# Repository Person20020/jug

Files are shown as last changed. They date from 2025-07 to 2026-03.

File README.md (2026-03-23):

Jug Logo wide no fill

# Jug

A 6x3 column staggered split keyboard with a large thumb cluster.



jug render

The jug is a 6x3 column staggered split keyboard with 46 keys. It has a 5 key thumb cluster extending out to reduce reaching back with your thumb. It uses USB C for interconnect and includes two indicator leds per side for caps/num lock and layer (eg. Colemak vs QWERTY).

The PCB supports both hotswap sockets and directly soldering the switches. It is fully reversible and uses soldered jumpers for the MCU, a RP2040 Zero.

All components are placed so that the case sides are exact mirrors.

pcb
schematic
routing

## Parts

### Electronics

| Part | Count | Price ($) | Link |
| --- | ----- | --- | --- |
| RP2040 Zero | 2 | ~4 each | |
| MX Switches | 46 | ~20-30 | |
| Hotswap Sockets (optional) | 46 | ~10 for 70 on AliExpress | |
| 1n4148 Diodes | 46 | ~2 for 100 on AliExpress | |
| USB C Ports | 2 | 0.40 (5 min order on lcsc) | [https://lcsc.com/product-detail/image/GT-USB-7010ASV_C2988369.html](https://lcsc.com/product-detail/image/GT-USB-7010ASV_C2988369.html) |
| 1206 SMD LEDs (I used red and blue leds) | 4 | 0.42 (100 min order on lcsc) | [blue](https://lcsc.com/product-detail/image/XL-3216UBC_C965827.html) or [red](https://lcsc.com/product-detail/image/XL-1608SURC-06_C965799.html)  |
| 1206 35.7 ohm SMD Resistors | 4 | 0.18 | [https://lcsc.com/product-detail/image/RC1206FR-0735R7L_C488810.html](https://lcsc.com/product-detail/image/RC1206FR-0735R7L_C488810.html) |
| 1206 5.1k ohm SMD Resistors | 2 | 0.22 | [https://lcsc.com/product-detail/image/FRC1206J512-TS_C2907509.html](https://lcsc.com/product-detail/image/FRC1206J512-TS_C2907509.html) |

### Other

| Part | Count |
| --- | ----- |
| 1u Keycaps | 42 |
| 1.5u Keycaps | 4 |
| 8mm m2 Standoffs | 14 |
| m2 x 4mm Screws | 28 |
| m2 x 12mm Screws | 4 |
| m3 x 12mm Screws | 12 |
| m3 Heat Set Inserts (5mm OD, 4mm L) | 12 |

I used socket head screws with hex drives. For the m2 screws screwed into the standoffs on the top (from the plate side, there are 14 of these) you will need to have screws that have a low enough head so that they don't hit the keycaps. I used [these](https://www.aliexpress.us/item/3256804883804669.html).

If you don't want to buy keycaps you can also print some like the [ScottoCaps](https://github.com/joe-scotto/scottokeebs/tree/main/Extras/ScottoCaps).

## Case

The case can be printed in its provided orientation, with the bottom to the build plate. The screw holes have sacrificial bridges in them to allow it to print cleanly. After printing, use a knife to cut through them. Other than that there should be no cleanup necessary.

## Firmware

I made both plain QMK and a Vial version of the firmware. They both have Colemak for the base layer with QWERTY as a second layer. You can set QWERTY as the base layer by moving the ` = 0` to `_QWERTY` from `_COLEMAK` in the keymap.c file, changing this:

```
enum layer_number {
    _COLEMAK = 0,
    _QWERTY,
    _LOWER,
    _RAISE,
    _ADJUST
};
```

to this:

```
enum layer_number {
    _COLEMAK,
    _QWERTY = 0,
    _LOWER,
    _RAISE,
    _ADJUST
};
```

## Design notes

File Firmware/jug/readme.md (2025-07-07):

# jug

jug

*A short description of the keyboard/project*

* Keyboard Maintainer: [Koji Ino](https://github.com/Person20020)
* Hardware Supported: *The PCBs, controllers supported*
* Hardware Availability: *Links to where you can find this hardware*

Make example for this keyboard (after setting up your build environment):

    make jug:default

Flashing example for this keyboard:

    make jug:default:flash

See the [build environment setup](https://docs.qmk.fm/#/getting_started_build_tools) and the [make instructions](https://docs.qmk.fm/#/getting_started_make_guide) for more information. Brand new to QMK? Start with our [Complete Newbs Guide](https://docs.qmk.fm/#/newbs).

## Bootloader

Enter the bootloader in 3 ways:

* **Bootmagic reset**: Hold down the key at (0,0) in the matrix (usually the top left key or Escape) and plug in the keyboard
* **Physical reset button**: Briefly press the button on the back of the PCB - some may have pads you must short instead
* **Keycode in layout**: Press the key mapped to `QK_BOOT` if it is available

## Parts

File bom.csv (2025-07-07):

Part | LCSC Part # | Quantity | Price (per unit) ($) | Price (total) ($) | Link | Note
RP2040 Zero | C5350143 | 2 | 5.1365 | 10.27 | https://lcsc.com/product-detail/Development-Boards-Kits_Waveshare-RP2040-Zero_C5350143.html
MX Switches |  | 46 (45 per pkg = 2 pkgs) | 0.311 | 27.98 (13.99/pkg) | https://www.amazon.com/Akko-Keyboard-Mechanical-Switches-Pre-Lubed/dp/B0D3D29G3T/
Hotswap Sockets |  | 46 (70 pcs for $6.15) | ~0.088 | ~6.15 | https://www.aliexpress.us/item/3256806866334888.html | Already have
1n4148 Diodes | C84410 | 46 | 0.0149 | 0.745 |  | Already have
USB-C ports | C720525 | 2 (5 min order) | 0.1399 | 0.70 | https://lcsc.com/product-detail/USB-Connectors_G-Switch-GT-USB-7010ASV_C2988369.html
1206 LEDs---
Red | C965799 | 2 (100 min order) | 0.0032 | 0.32 | https://lcsc.com/product-detail/image/XL-1608SURC-06_C965799.html
Blue | C965827 | 2 (100 min order) | 0.0084 | 0.42 | https://lcsc.com/product-detail/image/XL-3216UBC_C965827.html
1206 35.7 ohm resistors | C488810 | 4 (100 min order) | 0.0018 | 0.18 | https://lcsc.com/product-detail/image/RC1206FR-0735R7L_C488810.html
1206 5.1k ohm resistors | C2907509 | 2 (100 min order) | 0.0022 | 0.22 | https://lcsc.com/product-detail/image/FRC1206J512-TS_C2907509.html
Hardware---- | All screws are hex socket head
8mm m2 standoffs |  | 14 |  |  |  | Already have
m2 x 4mm screws |  | 28 |  |  |  | Already have
m2 x 12mm screws |  | 4 |  |  |  | Already have
m3 x 12mm screws |  | 12 |  |  |  | Already have
m3 heat set inserts |  | 12 (50 per pkg) | 0.5408 | 6.49 | https://www.amazon.com/uxcell-Threaded-Inserts-Knurled-Printing/dp/B0DC41PRRC/
Other----
1u Keycaps |  | 42 (24 per pkg = 2 pkgs) | 0.3746 | 17.98 (8.99 per pkg) | https://www.amazon.com/Mechkeeb-Profile-Switches-Keyboard-Replacement/dp/B0BWDQ3NKK/
1.5u Keycaps |  | 4 (10 per pkg) | 0.772 | 7.72 | https://www.amazon.com/JAGTRADE-Keycaps-Profile-Mechanical-Keyboard/dp/B0CS5VCVJ4/
Flux syringe (for soldering smd usb) |  | 1 | 9.99 | 9.99 | https://www.amazon.com/gp/product/B0D2DFKC5N/
PCB |  | 5 |  | 11.70+16.36shipping+fees=29.84
 |  | lcsc shipping 17.13
 | amazon 64.05 | lcsc 31.99 | jlcpcb 29.84
Total purchased price | $125.88
Total | $132.78

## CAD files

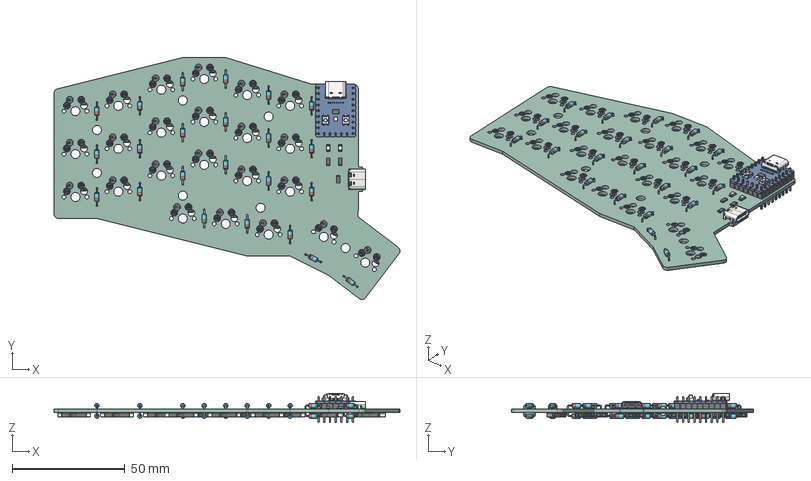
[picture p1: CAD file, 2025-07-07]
PCB/jug/jug.step
153.5 x 107.4 x 12.9 mm
USB_C_Receptacle_GCT_USB4105-xx-A_16P_TopMnt_Horizontal
Hotswap_MX x 23
Double_Side_Diode_DO-35 v1 x 23
R_1206_3216Metric x 6
LED_1206_3216Metric x 4
Raspberry_Pi_Pico.step
PinHeader_1x20_P2.54mm_Vertical.step
BOARD
ANSCHL_X_FCSSE_009
K_X_F6RPER_009
ANSCHL_X_FCSSE_010
K_X_F6RPER_010
EXTRUDED-32530
USER_LIBRARY-CHIP_CAP_MLCC_0219
USER_LIBRARY-CHIP_CAP_MLCC_0220
USER_LIBRARY-CHIP_CAP_MLCC_0221
USER_LIBRARY-CHIP_CAP_MLCC_0222
EXTRUDED-36548
USER_LIBRARY-RP2040_QFN56_04
USER_LIBRARY-8MA3_1
USER_LIBRARY-8MA3_2
EXTRUDED-175432
EXTRUDED-175808
EXTRUDED-175809
EXTRUDED-175810
EXTRUDED-175811
EXTRUDED-175812
ANSCHL_X_FCSSE_011
K_X_F6RPER_011
ANSCHL_X_FCSSE_012
K_X_F6RPER_012
ANSCHL_X_FCSSE_013
K_X_F6RPER_013
ANSCHL_X_FCSSE_014
K_X_F6RPER_014
ANSCHL_X_FCSSE_015
K_X_F6RPER_015
ANSCHL_X_FCSSE_016
K_X_F6RPER_016
ANSCHL_X_FCSSE_017
K_X_F6RPER_017
TS-1185EC-A-E-A-002
TS-1185EC-A-E-A-003
USER_LIBRARY-CHIP_CAP_MLCC_0223
USER_LIBRARY-CHIP_CAP_MLCC_0224
USER_LIBRARY-CHIP_CAP_MLCC_0225
USER_LIBRARY-CHIP_CAP_MLCC_0226
USER_LIBRARY-CHIP_CAP_MLCC_0227
USER_LIBRARY-CHIP_CAP_MLCC_0228
USER_LIBRARY-CHIP_CAP_MLCC_0229
USER_LIBRARY-CHIP_CAP_MLCC_0230
USER_LIBRARY-CHIP_CAP_MLCC_0231
USER_LIBRARY-CHIP_CAP_MLCC_0232
USER_LIBRARY-CHIP_CAP_MLCC_0233
USER_LIBRARY-CHIP_CAP_MLCC_0234
USER_LIBRARY-CHIP_CAP_MLCC_0235
USER_LIBRARY-CHIP_CAP_MLCC_0236
USER_LIBRARY-CHIP_CAP_MLCC_0237
EXTRUDED-374547
EXTRUDED-374548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

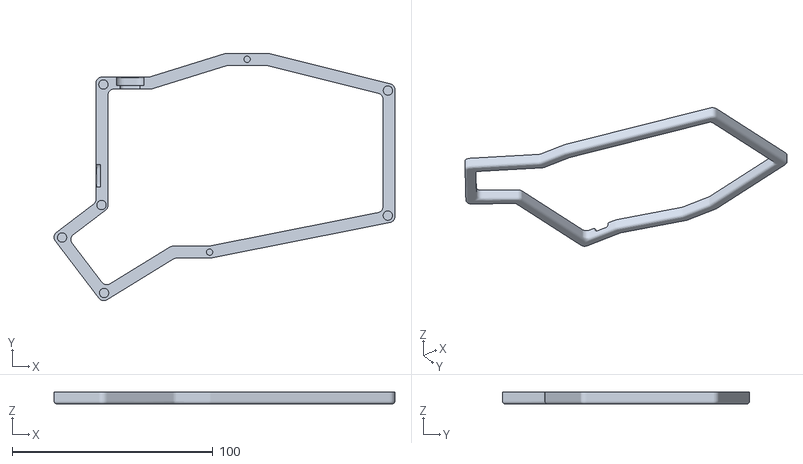
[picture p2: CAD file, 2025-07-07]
Case/Jug--Case Top-Left.stl
169.9 x 123.3 x 6.00

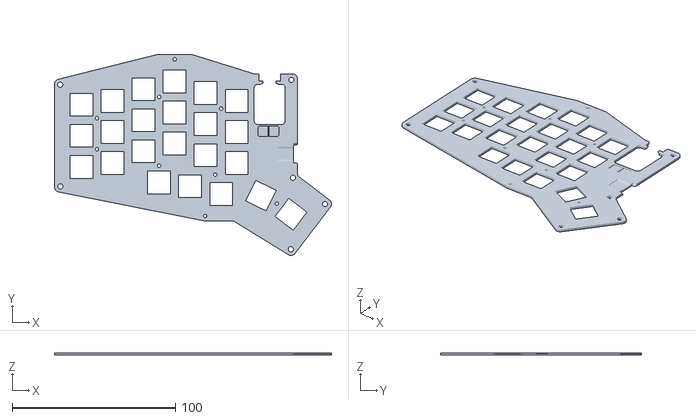
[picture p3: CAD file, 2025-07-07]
Case/Jug--Plate-Right.stl
169.9 x 123.3 x 1.50

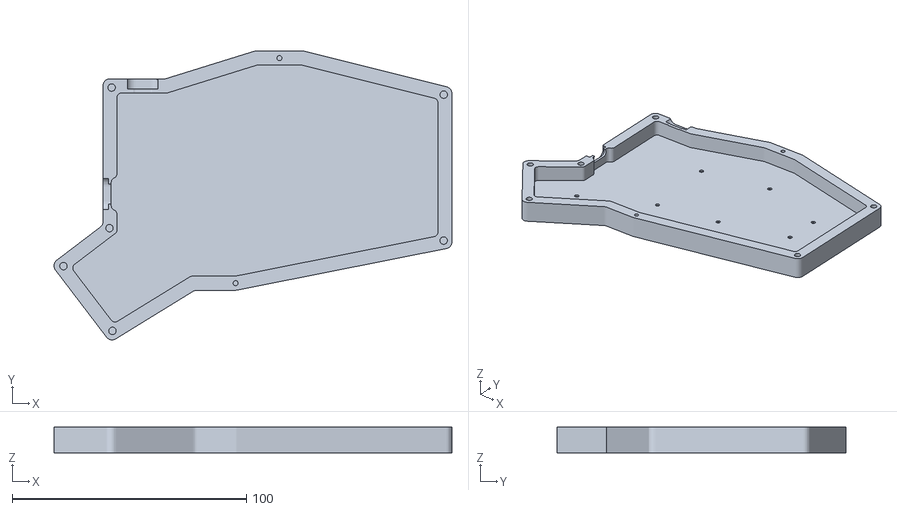
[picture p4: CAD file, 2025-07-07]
Case/Jug--Case Bottom-Right.stl
169.9 x 123.3 x 11.0

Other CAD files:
Case/Jug--Assembly.step
Case/Jug--Case Top-Right.stl
Case/Jug--Plate-Left.stl
Case/Jug--Case Bottom-Left.stl
Case/Jug Case v19.f3z

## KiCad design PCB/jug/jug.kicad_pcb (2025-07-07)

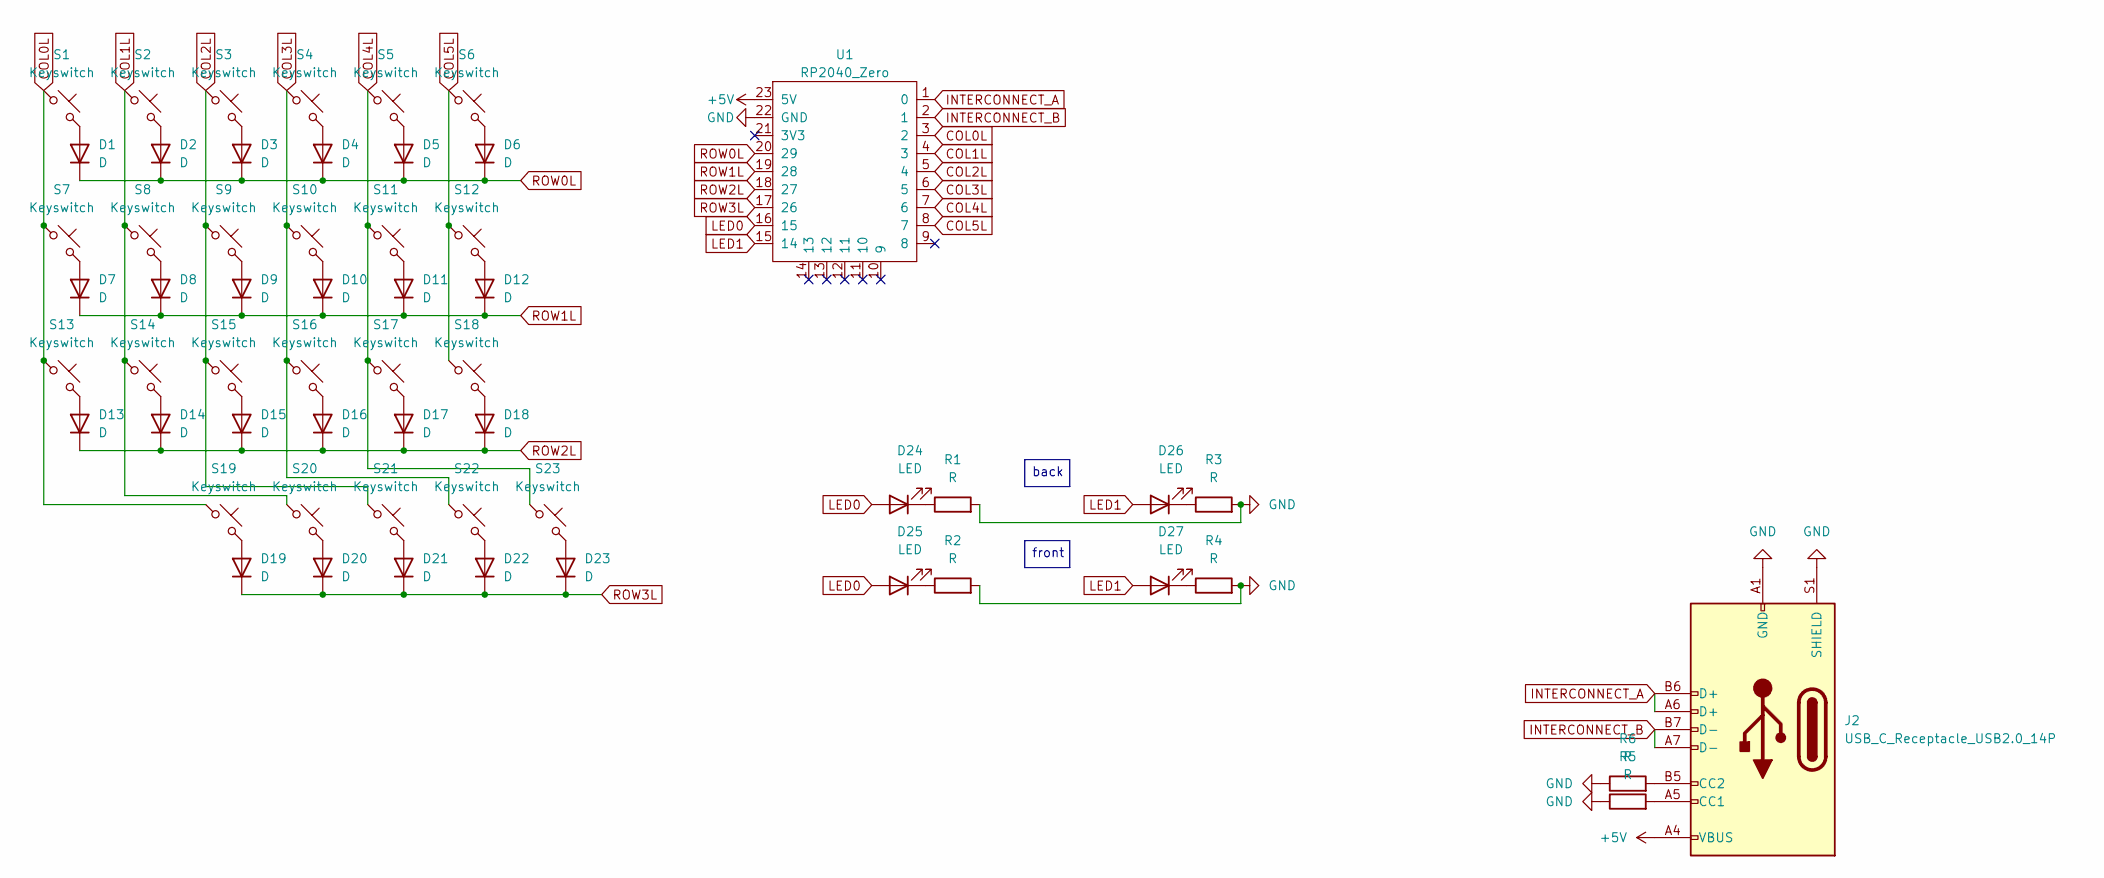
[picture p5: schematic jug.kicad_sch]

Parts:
D1, D2, D3, D4, D5, D6, D7, D8, D9, D10, D11, D12, D13, D14, D15, D16, D17, D18, D19, D20, D21, D22, D23: D; Double_Sided_Diode_DO-35
D24, D25, D26, D27: LED; LED_1206_3216Metric_Pad1.42x1.75mm_HandSolder
J2: USB_C_Receptacle_USB2.0_14P; USB_C_Receptacle_G-Switch_GT-USB-7010ASV_Double-Sided
R1, R2, R3, R4, R5, R6: R; R_1206_3216Metric_Pad1.30x1.75mm_HandSolder
S1, S2, S3, S4, S5, S6, S7, S8, S9, S10, S11, S12, S13, S14, S15, S16, S17, S18, S19, S20, S21: Keyswitch; Hotswap_MX_Plated_1.00u_Reversible
S22, S23: Keyswitch; Hotswap_MX_Plated_1.50u_90deg_Reversible
U1: RP2040_Zero; RP2040_Zero_Reversible

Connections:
+5V: J2.A4 (VBUS), J2.A9 (VBUS), J2.B4 (VBUS), J2.B9 (VBUS), U1.23 (5V)
COL0L: S1.1, S7.1, S13.1, S19.1, U1.3 (2)
COL1L: S2.1, S8.1, S14.1, S20.1, U1.4 (3)
COL2L: S3.1, S9.1, S15.1, S21.1, U1.5 (4)
COL3L: S4.1, S10.1, S16.1, S22.1, U1.6 (5)
COL4L: S5.1, S11.1, S17.1, S23.1, U1.7 (6)
COL5L: S6.1, S12.1, S18.1, U1.8 (7)
GND: J2.A1 (GND), J2.A12 (GND), J2.B1 (GND), J2.B12 (GND), J2.S1 (SHIELD), R1.2, R2.2, R3.2, R4.2, R5.1, R6.1, U1.22 (GND)
INTERCONNECT_A: J2.A6 (D+), J2.B6 (D+), U1.1 (0)
INTERCONNECT_B: J2.A7 (D-), J2.B7 (D-), U1.2 (1)
LED0: D24.2 (A), D25.2 (A), U1.16 (15)
LED1: D26.2 (A), D27.2 (A), U1.15 (14)
unnamed: D1.2 (A), S1.2
unnamed: D2.2 (A), S2.2
unnamed: D3.2 (A), S3.2
unnamed: D4.2 (A), S4.2
unnamed: D5.2 (A), S5.2
unnamed: D6.2 (A), S6.2
unnamed: D7.2 (A), S7.2
unnamed: D8.2 (A), S8.2
unnamed: D9.2 (A), S9.2
unnamed: D10.2 (A), S10.2
unnamed: D11.2 (A), S11.2
unnamed: D12.2 (A), S12.2
unnamed: D13.2 (A), S13.2
unnamed: D14.2 (A), S14.2
unnamed: D15.2 (A), S15.2
unnamed: D16.2 (A), S16.2
unnamed: D17.2 (A), S17.2
unnamed: D18.2 (A), S18.2
unnamed: D19.2 (A), S19.2
unnamed: D20.2 (A), S20.2
unnamed: D21.2 (A), S21.2
unnamed: D22.2 (A), S22.2
unnamed: D23.2 (A), S23.2
unnamed: D24.1 (K), R1.1
unnamed: D25.1 (K), R2.1
unnamed: D26.1 (K), R3.1
unnamed: D27.1 (K), R4.1
unnamed: J2.A5 (CC1), R5.2
unnamed: J2.B5 (CC2), R6.2
ROW0L: D1.1 (K), D2.1 (K), D3.1 (K), D4.1 (K), D5.1 (K), D6.1 (K), U1.20 (29)
ROW1L: D7.1 (K), D8.1 (K), D9.1 (K), D10.1 (K), D11.1 (K), D12.1 (K), U1.19 (28)
ROW2L: D13.1 (K), D14.1 (K), D15.1 (K), D16.1 (K), D17.1 (K), D18.1 (K), U1.18 (27)
ROW3L: D19.1 (K), D20.1 (K), D21.1 (K), D22.1 (K), D23.1 (K), U1.17 (26)

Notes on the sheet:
back
front

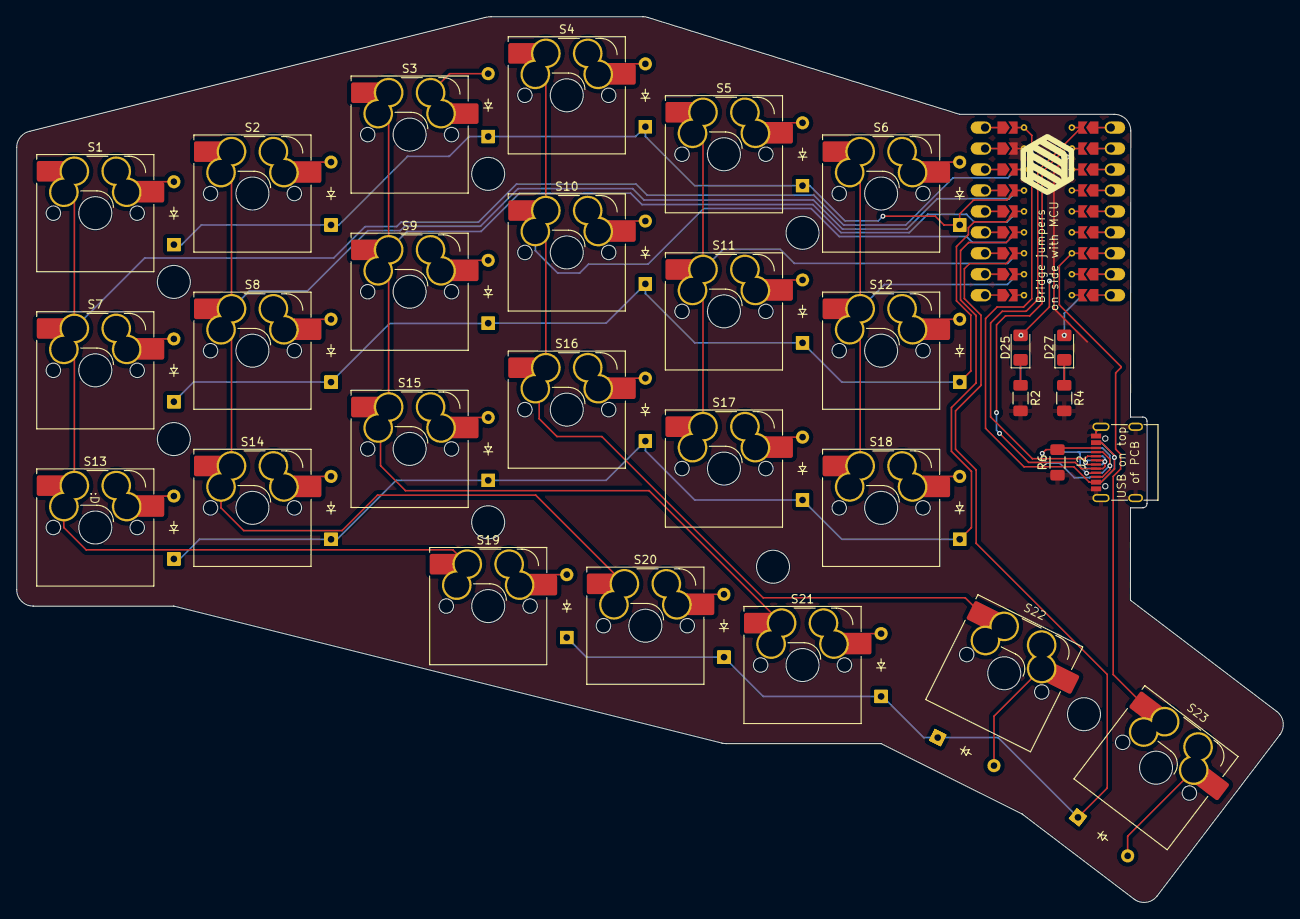
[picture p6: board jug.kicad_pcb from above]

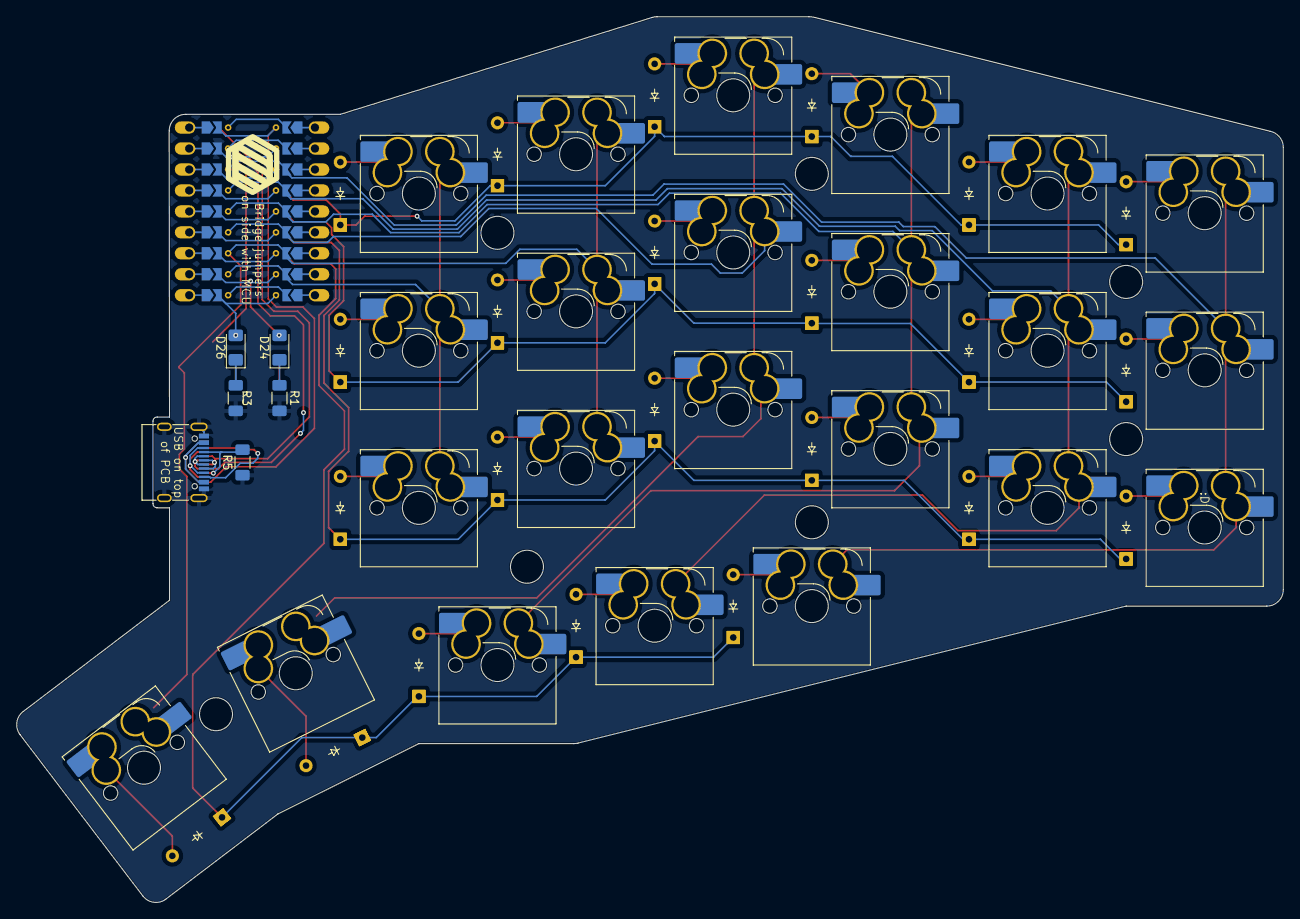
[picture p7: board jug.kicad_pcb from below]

Board: 2 copper layers, 153.5 x 107.4 mm, 58 parts (5 on the bottom side), 45 nets.

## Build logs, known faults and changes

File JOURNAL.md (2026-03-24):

---
show_on_site: True
title: "Jug"
author: "Person20020"
description: "A 6x3 column staggard split keyboard with a large thumb cluster."
created_at: "2025-05-20"
start_date: "2025-05-20"
total_time_spent: 50
image_url: "https://cdn.hackclub.com/rescue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"
image_url_alt: "The fully assembled keyboard"
---

# Jug -- Split Keyboard

# June 20: Made KLE and printed a test plate

This project I started a while ago for hackboard, but I redid the entire thing several times and never finished. I'm restarting from scratch again and today I made an approximate keyboard layout and printed out a plate to see how the layout felt.




When I was making it for hackboard I had originally thought I would make a 4x6 board with a medium sized thumb cluster (4 keys and changed to 5 later) but I'm now going to make it with 6 thumb keys and the main part will be 3x6 instead. 

The first plate I printed as a test (from hackboard) looked like this (I hadn't finished the thumb cluster layout):



But this is the one I printed out today:

new plate
new plate
new plate
new plate

After printing it out and looking at the layout, I also decided I won't include an encoder because it sticks up way too much. I will probably put the interconnect where the encoder is. (I was going to use 4p4c but the connectors look kind of large. Maybe USB A. I have found double sided USB A cables on aliexpress and that shouldn't be confusing because only host should have USB A so it should be clear that it is for a different purpose.)

The stagger from hte middle finger to pointer finger and ring finger to pinky finger is a bit too large so I will reduce it a bit. I also found that the farthest out key on the thumb cluster is rather hard to reach so I might remove that as well. It should make the keyboard more compact which will be nice.

Here is a comparison between the new keyboard and my Lily58:

comparison between lily58 and jug

I also spent a bunch of time troubleshooting why Fusion wouldn't export and it seems like it was because my virtual machine wasn't able to fully connect to the internet because something was wrong with the DNS. I just changed it to cloudflare in Windows and it seems be fixed.

I'm not fully set on my keyboard's name but I think jug makes sense because it looks kind of like a jug/pitcher with a long spout.

**Total time spent: 5hr**

# June 28: Modified KLE + redesigned plate

Today I modified the KLE to change the key stagger, removed one thumb key, and redid the thumb row. I moved the whole thumb cluster about 1/2 keys over. I changed all of the thumb keys to be 1u (I had one key that would be 1.25 before). I also removed the spot for the encoder and made a small recess so I could put the rp2040 pro micro and see how the spacing would be.

plate in fusion
printed plate on bed
with keycaps
next to lily58

I then did a test print to feel the spacing of the keys. The main part of the keyboard feels good now. The part of the thumb cluster that is under the main part of the board is pretty good but the thumb keys that are farthest out I think would be better if it was rotated more.

**Total time spent: 4hr**

# June 28-second: adjusted thumb cluster + first pcb design

I adjusted the thumb cluster by rotating the end keys more so that they are angled like the big key on the lily58. The layout feels really good now. I next started working on the pcb layout. I did the main layout but I'm not sure yet if I want to use RGB or not. I think I'll probably at least add a few leds for caps lock/num lock. I also printed out 2 1.5u keys to see how they look and I'll be using that in my design.

new more angled thumb

After doing the test print (the placement is good) I started working on the pcb. I made the whole pcb for the left side.

first pcb

**Total time spent: 3hr**

# June 29: Made reversible footprint for plated hotswap + work on pcb

I decided I want to make the pcb reversible so I made a footprint for hotswap sockets that can also be used to solder the switches in place. It is based on the plated ScottoKeebs footprints but should work flipped as well. I also decided I won't add rgb because routing would be especially annoying with the reversible footprints taking up so much extra space.

reversible plated hotswap footprints

I also made a diode footprint with the silkscreen on both sides and the model showing on both sides.

double sided diode

After making the footprints I redid the pcb again. I was a bit confused about how the reversible footprint I found for the mcu works but it seems like you just solder the jumpers on the side that the mcu faces. (the side that the side of the mcu with the components faces.)

routed pcb

There were some errors on the mcu footprint but I think that it is just because the jumpers have a gap between them that doesn't have solder mask and it thinks it will cause a short. I can't figure out how to get rid of the errors but it should be fine.

**Total time spent: 5hr**

# June 29: Made USB A interconnect reversible

I had forgotten that I wouldn't be able to reverse the USB A connector for the interconnect so I spent a while fixing that. I used the same method with solder jumpers as for the mcu and it was really confusing. As I understand it this should work to make rotating the connector (flipping the side of the board it is on) work.

reversible usb schematic

After figuring out that I also added holes for standoffs to pass through to support the plate.

**Total time spent: 4hr**

# July 1: Added indicator leds and worked on firmware

Today I added indicator leds. They are small 1206 smd leds so that hey can fit under the plate and diffuse through. There will be two leds per side (one red and one blue). One on each side will be an indicator for either caps lock or num lock and the other will be to indicate whether i'm in the colemak or qwerty layer.

final pcb

Yesterday I was working on my case but Fusion crashed and I lost all of my progress because the internet had just gone out.

The other thing I did today was work on firmware. I did all of my layers and am almost done. I will be adding vial support later but I'll do that after finishing the basic firmware.

**Total time spent: 5hr**

# July 1: Worked on firmware + added silkscreen to pcb

I added my logo + text to show which side to solder the jumpers for the mcu. I also learned that AliExpress won't ship to me anymore so I have switched from the RP2040 Pro Micro to the RP 2040 Zero. I made a reversible footprint for the MCU since I couldn't find one online.

reversible rp2040 zero footprint

I then had to re route part of the pcb after swapping out the footprint and then did a check over the whole thing. I added some silkscreen logo and text (to show which side to solder/place components on). This is (for real this time) the final version of the pcb:

final pcb

final pcb - 3d

**Total time spent: 6hr**

# July 3: Switched interconnect to USB C and worked on case

I decided that I would switch to use USB C for the interconnect because USB A-A cables aren't as common. They can be found on Amazon but basically everyone will have a USB C-C cable.

finished pcb for real this time

finished pcb - 3d

I worked on the case and finished almost the entire thing.

I forgot to get any pictures of the case.

**Total time spent: 5hr**

# July 4: Finished the case + QMK firmware

I finished working on the case. Because the pcb is reversible with the components staying in the exact same position, the right side will just be a mirror version of the case. 

case render

I added a recess in the plate above the indicator leds that should make them brighter in just that area and hopefully it will look nicer.

led indicator cutout

I also worked on my base QMK firmware and was able to compile the basic version that doesn't have combos or extra features. 

**Total time spent: 5hr**

# July 5: Worked on Vial firmware

I finished the Vial firmware and was able to flash it on another RP2040 board that I have and was able to short the pins to print out the keys on the left half. I also got vial itself working. I struggled a bunch because apparently the ordering of the matrix definitions really matters so all of the keys were mixed up. 

Vial

**Total time spent: 4hr**

# July 6: Worked on README and full parts list

Added all info to README and finished selecting parts.

**Total time spent: 4hr**

# July 23: Stuff arrived and started soldering.

All of my stuff arrived (other than a few keycaps which I can print myself). I started soldering the keyboard and finished one half. Everything seems to work quite well.

soldered pcb

I accidentally ordered 0603 red leds instead of 1206 so they are the wrong size for the footprint but I was still able to solder it in place with a big glob of solder.

0603 led

**Total time spent: 3hr**

# July 24: Soldered second half

Today I soldered the second half of the pcb. The reversible footprints all worked perfectly but after connecting the halves the second side wouldn't do anything. By itself it is able to type when directly connected to the computer but the USB C interconnect doesn't work. I tested with a multimeter and it seems like there is power on the second half and there is a connection between the two interconnect pins (between the halves) but it seems like there is some resistance on the interconnect line because I chose to use D+ which I think has some kind of active filtering or something?

**Total time spent: 4hr**

# July 25: Fixed interconnect

I did some testing and managed to get the halves to connect. I used a alligator clip jumper wire to connect the interconnect pins and the keyboard worked. For a few seconds it also worked over just USB C but it stopped working and that hasn't happened again. 

temporary fix

I then melted a hole in the side of the case and soldered some wire on to each interconnect pin and brought the wire out the side. I crimped DuPont connectors on to each one so that I can change the length of the wire in the middle if I want.

finished keyboard

**Total time spent: 2hr**

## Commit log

2025-06-29 first version of pcb. only left side routed. uses non reversible footprint for switches.
    [bom.csv, jug.kicad_pcb, jug.kicad_sch]
2025-07-02 finished pcb with RP2040 Pro Micro
    [bom.csv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]
2025-07-02 changed mcu to rp2040 zero with reversible footprint
    [jug.kicad_pcb, jug.kicad_sch]
2025-07-03 finished pcb
    [bom.csv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]
2025-07-03 changed usb a to c
    [bom.csv, jug.kicad_pcb]
2025-07-07 everything finished
    [Jug Case v19.f3z, Jug--Assembly.step, Jug--Case Bottom-Left.stl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]
2025-07-07 added images of pcb design to readme
    [jug.kicad_sch]
